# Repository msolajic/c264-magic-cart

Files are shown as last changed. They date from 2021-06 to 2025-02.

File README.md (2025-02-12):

# c264-magic-cart
Hardware design of a cartridge for the Commodore 264 series of computers - Commodore 16, 116 and plus/4

This is the hardware part that accompanies the project of [Magic Cartridge Generator](https://bitbucket.org/zzarko/magic-cartridge-generator/)

This project is free to use and you can use any PCB manufacturer by downloading the Gerber files, but if you would like to support my work and help with further hardware development you can order these PCBs on PCBWay trough this link:

PCB from PCBWay (https://www.pcbway.com/project/shareproject/Commodore_264_Series_Magic_Cartridge.html)

You will get cheap and professionally made PCBs, I will get credits that will help with this and [other projects](https://www.pcbway.com/project/member/?bmbno=1DE407A1-1650-47). Also, if you have to register to that site, [you can use this link](https://pcbway.com/g/YFnBAc) to get bonus initial credit.

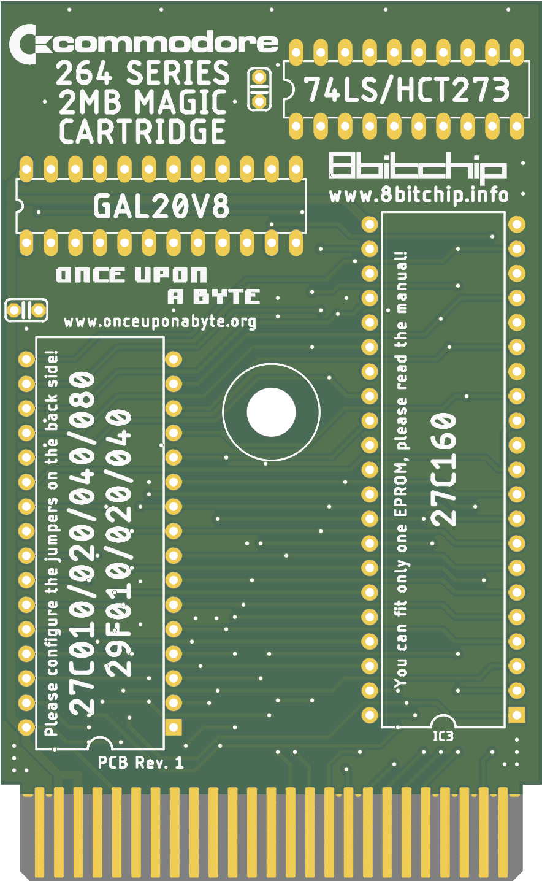
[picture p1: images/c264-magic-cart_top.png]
PCB Top


Hardware Description
--------------------

Original Commodore 264 cartridges could be up to 32 Kb in size, in two separate banks of 16Kb. This cartridge implements a latch which is tied to a memory address, so it can address (in this incarnation) up to 2 megabytes of data (128 banks of 16Kb). In that regard, it is very similar to Magic Desk or Ocean cartridges for the Commodore 64.

EPROM is selected by the C1LO selection line coming from the computer, and the 16k of data from the selected bank is visible in the memory map at addresses $8000 - $BFFF.

Inputs of an 8-bit latch (74LS273) are connected to the data lines. A GAL20V8 is responsible for decoding writes to a memory address by decoding the full address bus. Decoder has the option of decoding several frequently used addresses for banking cartridges, since there is no standard address defined. This cartridge is primarily designed to enable making onefile program compilations through the [Magic Cartridge Generator](https://bitbucket.org/zzarko/magic-cartridge-generator/).

The PCB was designed to accommodate various types of EPROMs and their FLASH variants. The smallest EPROM you can use is 27C010 (128Kb), and the largest is 27C160 (2Mb). There are two EPROM sockets, but you cannot use both at the same time. The left socket accepts standard 8-bit EPROMs and their FLASH variants (27C010 to 27C080) and the right socket is for 27C160 (16-bit EPROM in 8-bit mode).

Address decoder
---------------

The address decoder is implemented in GAL20V8. All 16 address lines, /PHI2 and /RW are connected to the GAL to enable single-address decoding. Of course, a GAL16V8 could have been used, but it would only be capable of decoding an address in 16-byte blocks, or the address decoder could be implemented in TTL logic which would require at least 3 ICs. Two spare inputs were used to create a selection jumper to select between four commonly used addresses for cartridge banking. The default address used is $FDFE, which is mentioned in the document at http://solder-synergy.de/plus4/hardware/makers/ioarea.txt as "Register on EPROM-card". Other addresses which can be configured are $FE00 (used on a Hungarian homebrew cartridge found at https://www.commodoreszerviz.hu/commodore_16-116-plus_4_1mb_cartridge_juhasz_jacint.htm), $FDA0 used by another homebrew cartridge, and $FD17 which is also mentioned in the document above as "Register for EPROM-/sRAM-expansion". 

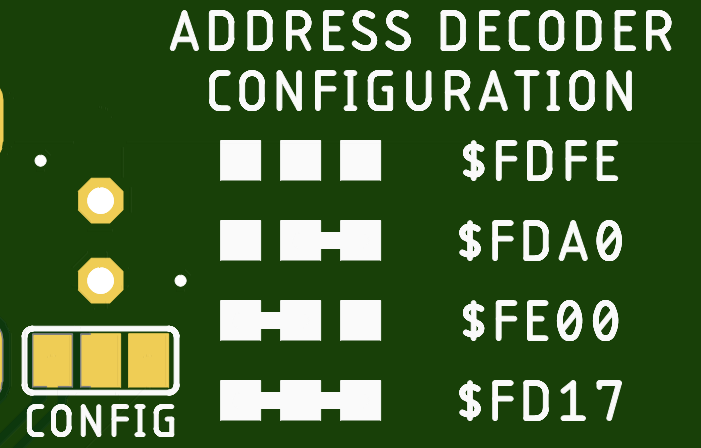
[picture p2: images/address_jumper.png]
Address selection jumper


The address decoder is configured with a solder-jumper on the bottom side of the PCB. The configuration legend is also shown at the bottom. Use extreme care when trying to bridge the pads (if needed, as the default configuration is already selected when the jumper is open) because you can easily lift the pads with excess heat.

EPROM selection jumpers
-----------------------

In order to support most common types of EPROMs and FLASH EPROMs, two solder jumpers have been placed on the bottom side of the PCB. They look like this:

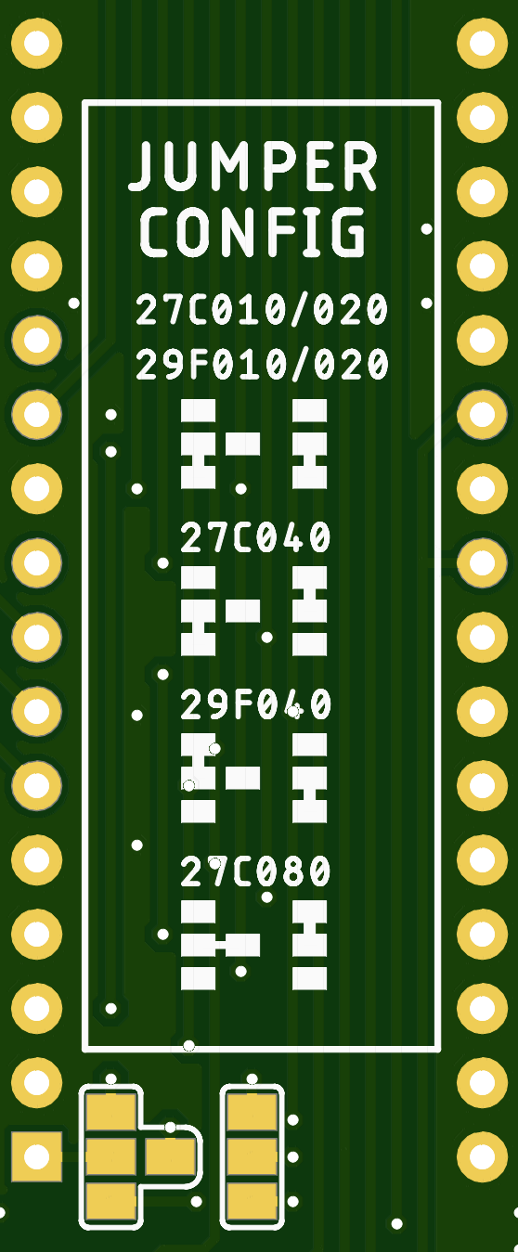
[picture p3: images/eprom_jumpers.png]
EPROM selection jumpers


These jumpers HAVE to be configured before plugging the cartridge to your computer! Different types of EPROMs and their FLASH variants have some pins swapped, and if you are using a chip smaller than the maximum size, the unused address lines have to be pulled high on the EPROM side to ensure proper functioning.

You can use either the left 32-pin socket, or the right 42-pin socket, but never the both at the same time. The right socket is meant for using the 2Mb 27C160 EPROMs. This is a 16-bit EPROM but it can be forced to work in 8-bit mode by connecting the BYTE/Vpp pin to ground. In that configuration, the address lines are shifted by one and the output Q15 is used as address line A0. These 16-bit EPROMs are not directly supported by the popular TL866 programmer, and have to be programmed through an adapter, in multiple passes. An example adapter can be found [here](https://github.com/mafe72/27c160-tl866-adapter) or [here](https://github.com/gaggi/27c160-tl866-adapter)

GAL programming
---------------

In the GAL folder there are both .pld and .jed files provided for GAL programming. You can also use a programmer such as TL866 to program the GAL. If you want to change anything in the decoder, you can use [GALASM](https://github.com/daveho/GALasm) to recompile the .pld file. 

Capacitors
----------

The capacitors are not needed, but you can populate them. They are 100nF 50V MLCC or ceramic capacitors with 2.54mm raster.

Enclosure compatibility
-----------------------

The PCB is designed to be as close in dimensions as the original Commodore PCB, so you can re-use an original Commodore cartridge case, or you can 3D-print one. Compatible designs are available on Thingiverse, such as [this one](https://www.thingiverse.com/thing:3657002) or [this one](https://www.thingiverse.com/thing:4627130). Unfortunately, no one makes injection-moulded cartridge cases for the 264 series anymore.

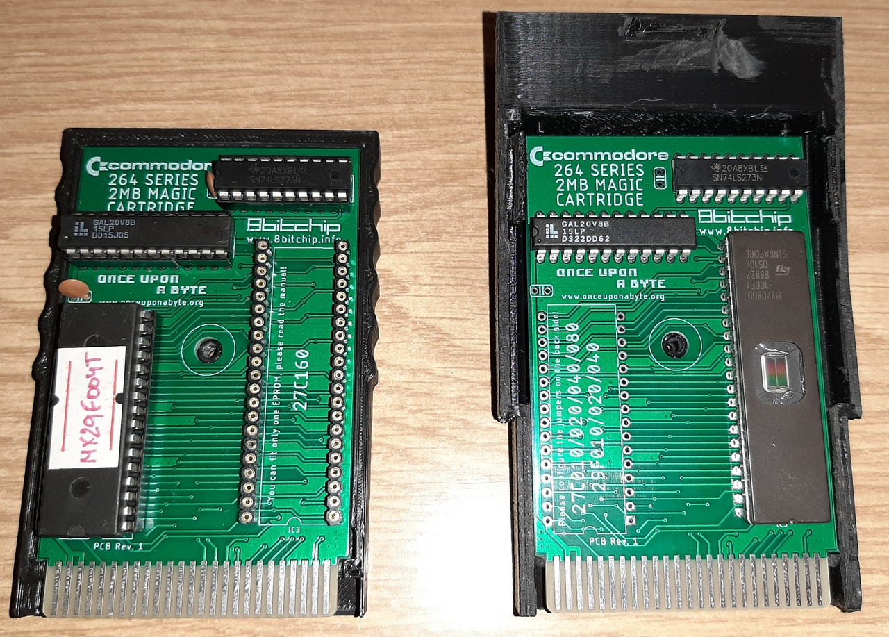
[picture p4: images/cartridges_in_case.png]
cartridges_in_case


Revision history
----------------

- Rev.1
    - Initial release

Changelog
---------

- February 11th, 2022:
    - Added EAGLE schematic and board files
    
Thanks:
-------

My thanks go to:

- Žarko Živanov, for creating the Magic Cartridge Generator
- Everyone from [Plus/4 World](http://plus4world.powweb.com/) for help with hardware and software specifics
- Groepaz from the [VICE Team](https://vice-emu.sourceforge.io/), for adding the cartridge support in VICE (currently available only in nightly builds)
- Jim Drew and the CRX crew
- Everyone who ordered any of my PCBs from PCBWay
- and all other people in the Commodore 64 community that I forgot to mention, you guys are awesome!

License
-------
c264-magic-cart is Open Hardware licensed under the [CERN OHL v. 1.2](http://ohwr.org/cernohl), released by Marko Šolajić in 2021. You may redistribute and modify this documentation under the terms of the CERN OHL v.1.2.

A copy of the full license is included in file [LICENSE.txt](LICENSE.txt)

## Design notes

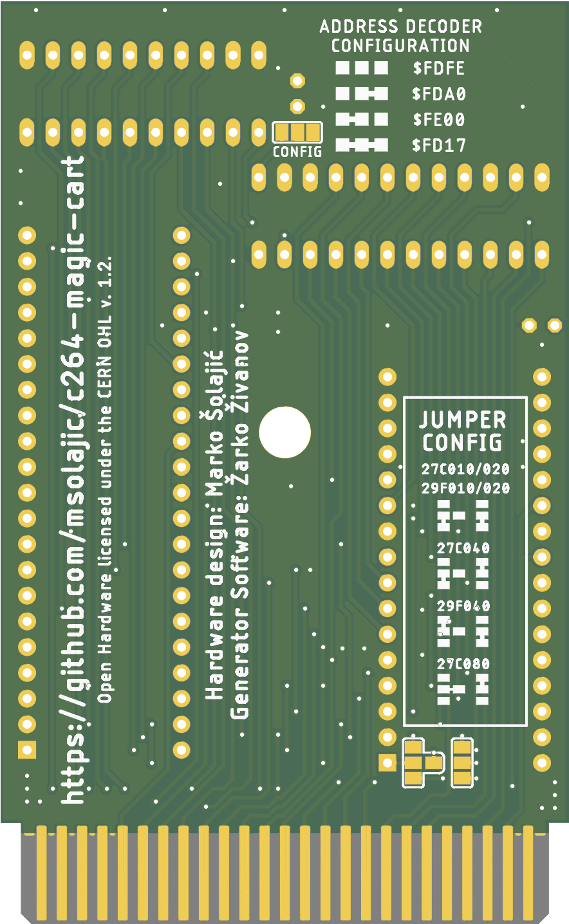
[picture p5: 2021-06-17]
images/c264-magic-cart_bot.png

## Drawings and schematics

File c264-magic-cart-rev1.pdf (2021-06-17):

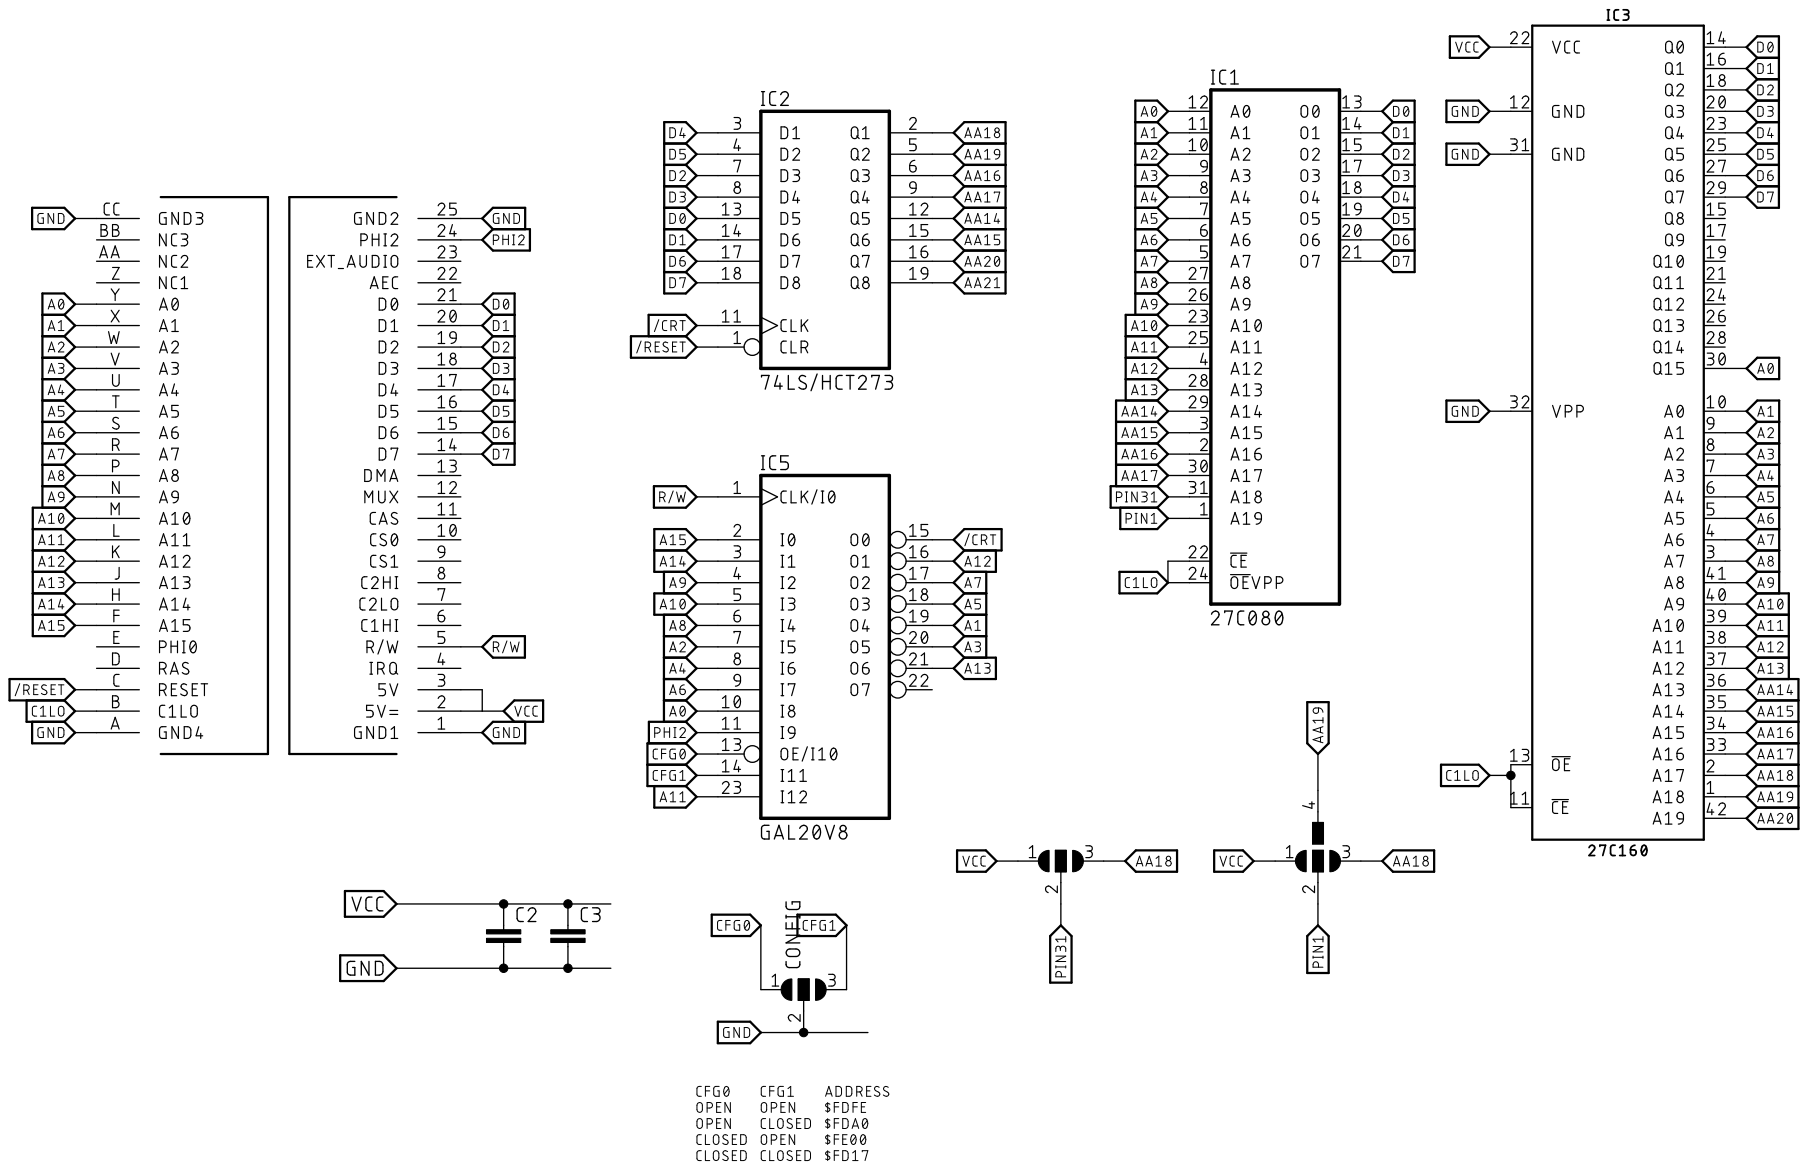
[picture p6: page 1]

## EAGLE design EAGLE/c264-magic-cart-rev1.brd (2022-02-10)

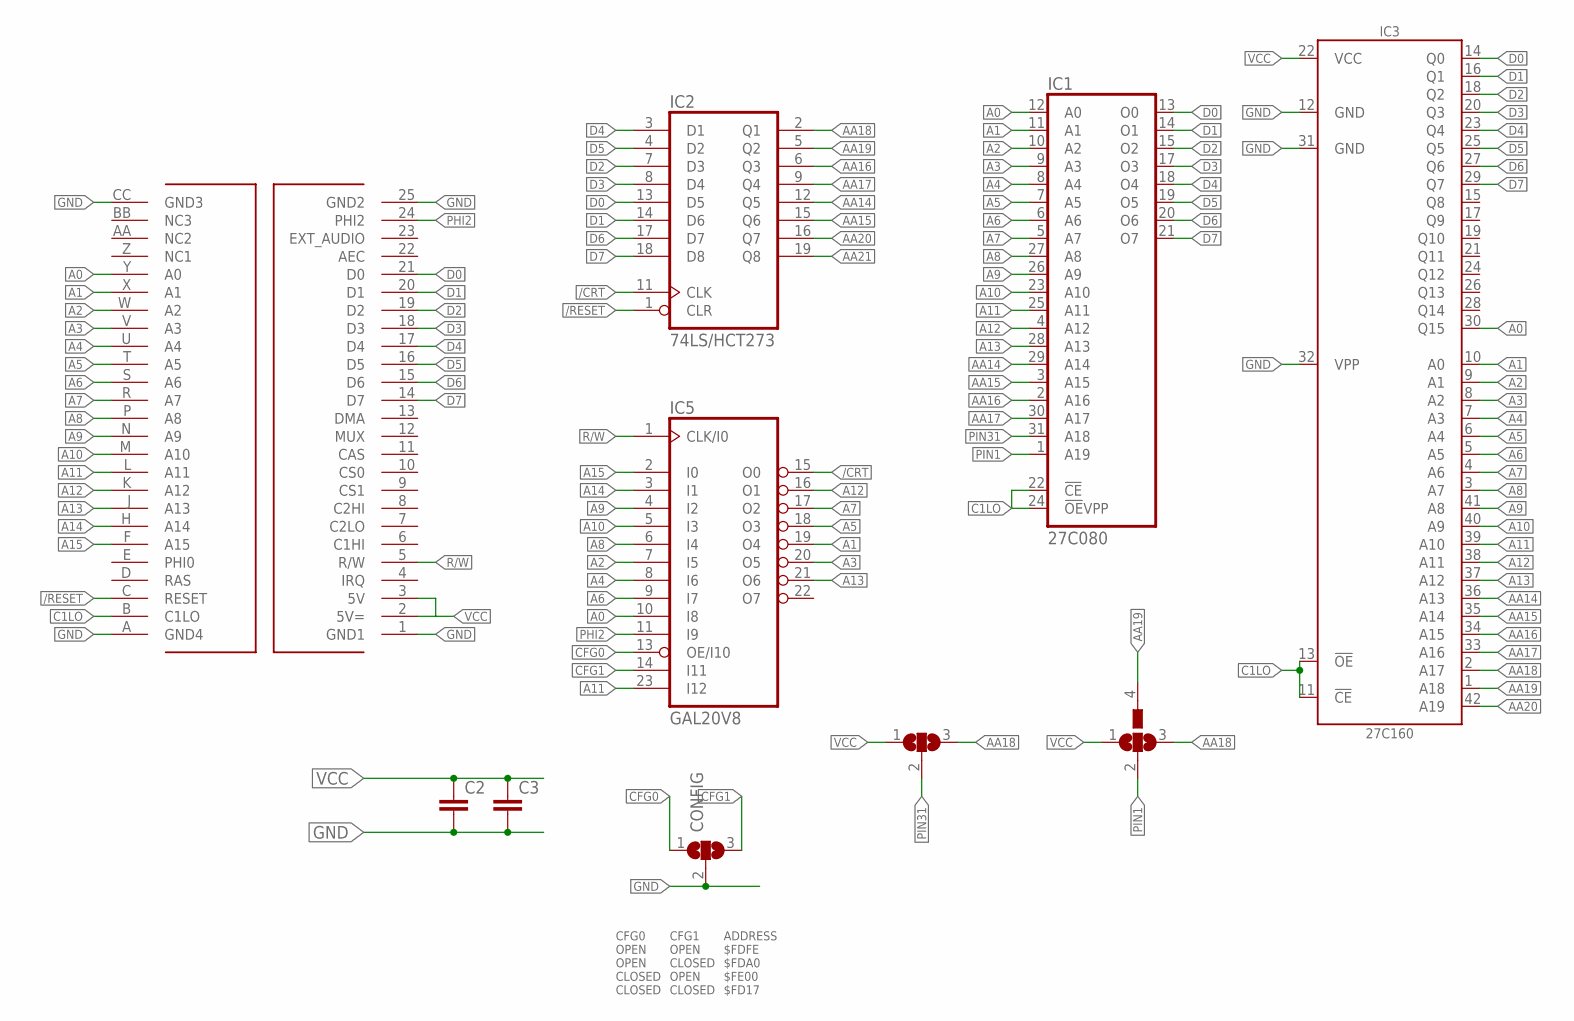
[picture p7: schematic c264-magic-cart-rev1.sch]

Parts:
C2, C3: C-EU025-024X044; C025-024X044
CONFIG: SJ2W; SJ_2
IC1: 27C080; DIL32
IC2: 74LS/HCT273; DIL20
IC3: 27C160; DIP42
IC5: GAL20V8; DIL24-3
SJ1: SJ2W; SJ_2
U$1: C16_CARTRIDGE; C16_CART
U$2: SJ3; SJ_3

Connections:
/CRT: IC2.11 (CLK), IC5.15 (O0)
/RESET: IC2.1 (CLR), U$1.C (RESET)
A0: IC1.12 (A0), IC3.30 (Q15), IC5.10 (I8), U$1.Y (A0)
A1: IC1.11 (A1), IC3.10 (A0), IC5.19 (O4), U$1.X (A1)
A2: IC1.10 (A2), IC3.9 (A1), IC5.7 (I5), U$1.W (A2)
A3: IC1.9 (A3), IC3.8 (A2), IC5.20 (O5), U$1.V (A3)
A4: IC1.8 (A4), IC3.7 (A3), IC5.8 (I6), U$1.U (A4)
A5: IC1.7 (A5), IC3.6 (A4), IC5.18 (O3), U$1.T (A5)
A6: IC1.6 (A6), IC3.5 (A5), IC5.9 (I7), U$1.S (A6)
A7: IC1.5 (A7), IC3.4 (A6), IC5.17 (O2), U$1.R (A7)
A8: IC1.27 (A8), IC3.3 (A7), IC5.6 (I4), U$1.P (A8)
A9: IC1.26 (A9), IC3.41 (A8), IC5.4 (I2), U$1.N (A9)
A10: IC1.23 (A10), IC3.40 (A9), IC5.5 (I3), U$1.M (A10)
A11: IC1.25 (A11), IC3.39 (A10), IC5.23 (I12), U$1.L (A11)
A12: IC1.4 (A12), IC3.38 (A11), IC5.16 (O1), U$1.K (A12)
A13: IC1.28 (A13), IC3.37 (A12), IC5.21 (O6), U$1.J (A13)
A14: IC5.3 (I1), U$1.H (A14)
A15: IC5.2 (I0), U$1.F (A15)
AA14: IC1.29 (A14), IC2.12 (Q5), IC3.36 (A13)
AA15: IC1.3 (A15), IC2.15 (Q6), IC3.35 (A14)
AA16: IC1.2 (A16), IC2.6 (Q3), IC3.34 (A15)
AA17: IC1.30 (A17), IC2.9 (Q4), IC3.33 (A16)
AA18: IC2.2 (Q1), IC3.2 (A17), SJ1.3, U$2.3
AA19: IC2.5 (Q2), IC3.1 (A18), U$2.4
AA20: IC2.16 (Q7), IC3.42 (A19)
AA21: IC2.19 (Q8)
C1LO: IC1.22 (!CE), IC1.24 (!OE!VPP), IC3.11 (!CE), IC3.13 (!OE), U$1.B (C1LO)
CFG0: CONFIG.1, IC5.13 (OE/I10)
CFG1: CONFIG.3, IC5.14 (I11)
D0: IC1.13 (O0), IC2.13 (D5), IC3.14 (Q0), U$1.21 (D0)
D1: IC1.14 (O1), IC2.14 (D6), IC3.16 (Q1), U$1.20 (D1)
D2: IC1.15 (O2), IC2.7 (D3), IC3.18 (Q2), U$1.19 (D2)
D3: IC1.17 (O3), IC2.8 (D4), IC3.20 (Q3), U$1.18 (D3)
D4: IC1.18 (O4), IC2.3 (D1), IC3.23 (Q4), U$1.17 (D4)
D5: IC1.19 (O5), IC2.4 (D2), IC3.25 (Q5), U$1.16 (D5)
D6: IC1.20 (O6), IC2.17 (D7), IC3.27 (Q6), U$1.15 (D6)
D7: IC1.21 (O7), IC2.18 (D8), IC3.29 (Q7), U$1.14 (D7)
GND: C2.2, C3.2, CONFIG.2, IC1.16 (GND), IC2.10 (GND), IC3.12 (GND), IC3.31 (GND), IC3.32 (VPP), IC5.12 (GND), U$1.1 (GND1), U$1.25 (GND2), U$1.A (GND4), U$1.CC (GND3)
PHI2: IC5.11 (I9), U$1.24 (PHI2)
PIN1: IC1.1 (A19), U$2.2
PIN31: IC1.31 (A18), SJ1.2
R/W: IC5.1 (CLK/I0), U$1.5 (R/W)
VCC: C2.1, C3.1, IC1.32 (VCC), IC2.20 (VCC), IC3.22 (VCC), IC5.24 (VCC), SJ1.1, U$1.2 (5V=), U$1.3 (5V), U$2.1

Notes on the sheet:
CFG0 OPEN OPEN CLOSED CLOSED
CFG1 OPEN CLOSED OPEN CLOSED
ADDRESS $FDFE $FDA0 $FE00 $FD17

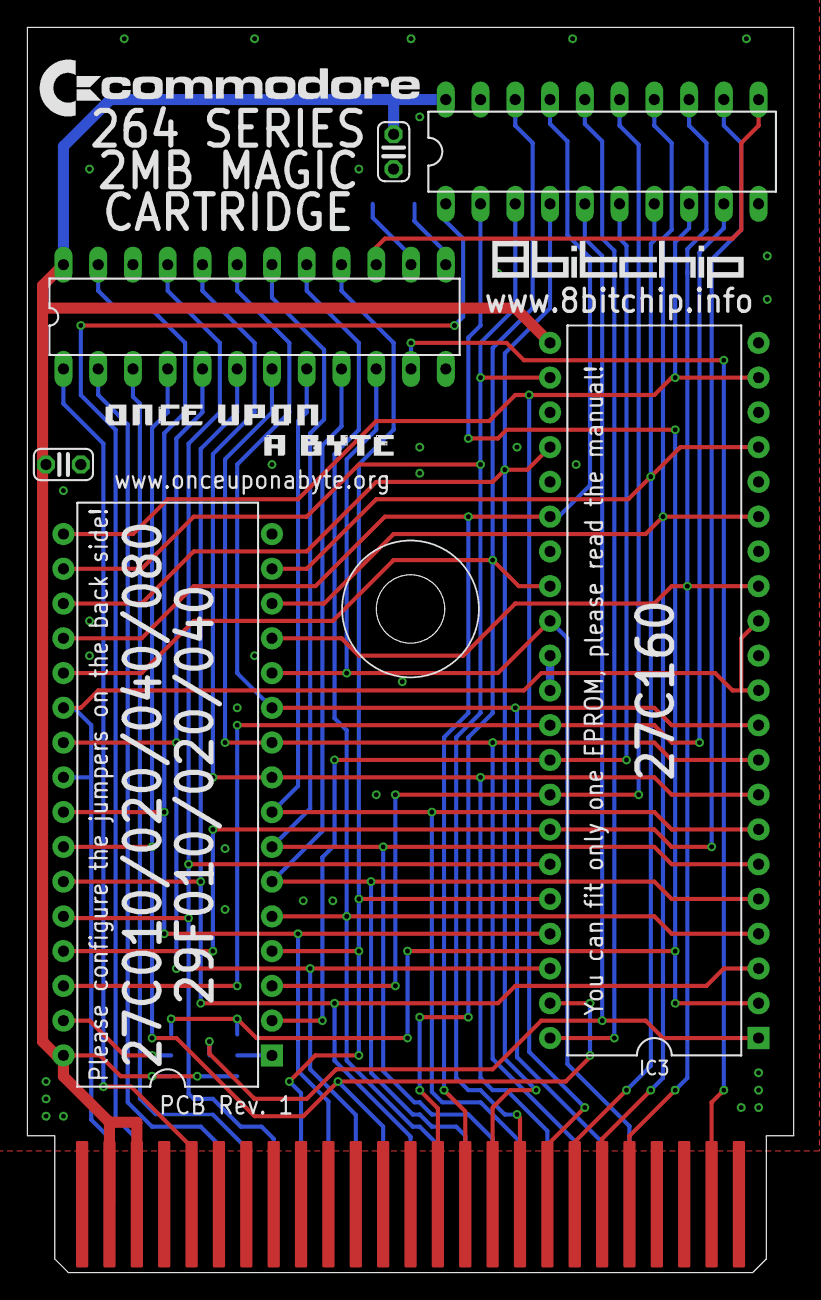
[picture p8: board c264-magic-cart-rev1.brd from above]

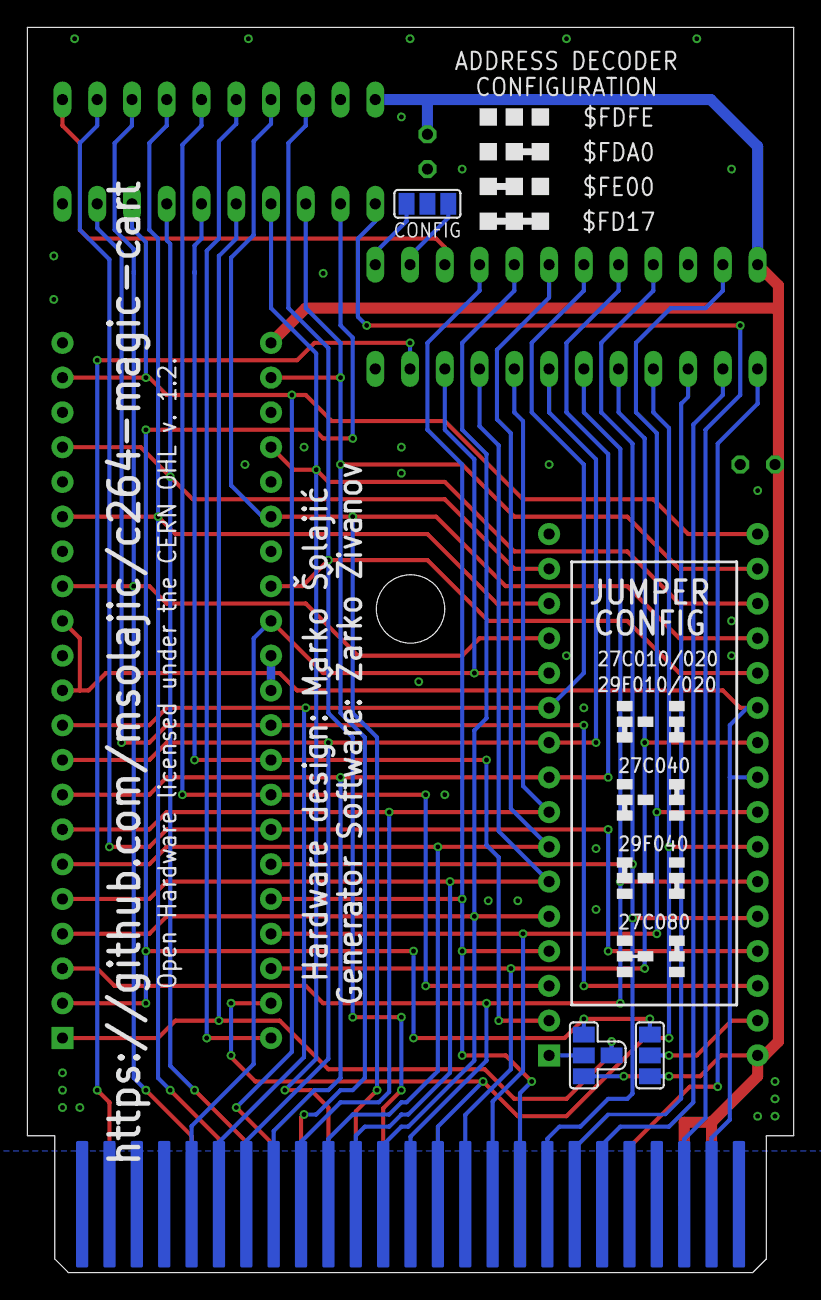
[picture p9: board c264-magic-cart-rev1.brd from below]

Board: 2 copper layers, 56.0 x 91.0 mm, 10 parts (3 on the bottom side), 42 nets.

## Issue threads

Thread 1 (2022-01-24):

Help me i can't get it to work

danko79, 2022-01-24:
Hi,i need help with this cartridge programmed the GAL20V8B-15LP set the jumpers for AM26F040B and make a 512KB file with prg games with zzarko-magic-cartridge-generator-fa8be5cd43f2 but when insert the cartridge it does not work, tested your other cartridges with success.

https://i.postimg.cc/tTB5dr2J/c264-front.jpg
https://i.postimg.cc/Y9rRWcNT/c264-back.jpg

msolajic, 2022-01-24:
Can you test the binary compilation file with VICE 3.6? This will rule out software issues, at least.

danko79, 2022-01-24:
Hi,yes test the .BIN file with GTK3VICE-3.6.0-win64 same
problem,attach the file .bin and .prg pack.
Please let me know!

Il
24.01.2022 14:03 Marko Šolajić ha scritto:

> Can you test the binary
compilation file with VICE 3.6? This will rule out software issues, at
least.
>
> --
> Reply to this email directly, view it on GitHub [1],
or unsubscribe [2].
> You are receiving this because you authored the
thread.Message ID: @github.com>

Con Tiscali Mobile Smart 70 hai 70 GB in 4G, minuti illimitati e 100 SMS a soli 7,99€ al mese http://tisca.li/Smart70

zzarko, 2022-01-24:
Can you send your whole directory with generator script, cartridge
configuration, prg files and generated BIN file? Then I can check what the
problem is.
Also, send the exact command line you used to generate BIN file.

Cheers,
Žarko

*Sent from my Commodore 64*

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

danko79, 2022-01-24:
ok the script is "python crtgen.py -c" in attach my directory,can you
create a file for me so i see if it works?

Il 24.01.2022 15:06 zzarko
ha scritto:

> Can you send your whole directory with generator script,
cartridge
> configuration, prg files and generated BIN file? Then I can
check what the
> problem is.
> Also, send the exact command line you
used to generate BIN file.
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
Commodore 64*
>
> On Mon, Jan 24, 2022 at 2:12 PM danko79 ***@***.***>
wrote:
>
> >
> > Hi,yes test the .BIN file with GTK3VICE-3.6.0-win64
same
> > problem,attach the file .bin and .prg pack.
> > Please let me
know!
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
rule out software issues, at
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
this email directly, view it on GitHub [1],
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
@github.com>
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
4G, minuti illimitati e 100 SMS a
> > soli 7,99EUR al mese
http://tisca.li/Smart70
> >
> > --
> > Reply to this email directly,
view it on GitHub
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
notifications on the go with GitHub Mobile for iOS
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
thread.Message
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
directly, view it on GitHub [1], or unsubscribe [2].
> You are receiving
this because you authored the thread.Message ID: @github.com>

Con Tiscali Mobile Smart 70 hai 70 GB in 4G, minuti illimitati e 100 SMS a soli 7,99€ al mese http://tisca.li/Smart70

zzarko, 2022-01-24:
Yes, that was exactly why I wanted to see the exact command line. "-p" is
the correct option.

Regarding the games that do not work, I found these:
Auto Zone.prg
Exploding Fist.prg
Invaders Live Wire.prg
Joey.prg
Kane.prg
Kingsoft Tennis.prg
Leapinlouie.prg
Monkey Kong.prg
Monster Hunter.prg
Oneman And His Droid.prg
Pac Mac.prg
Return Of Rockman.prg

Some of them have non-standard loading address (standard is $1001 or
$4001), for those you need to supply start address:
Invaders Live Wire.prg
Kingsoft Tennis.prg
Monkey Kong.prg

As for the rest, they do not work in xplus4 emulator (3.6.1) at all (at
least on my computer, when started directly as PRG files), so there is no
way that they could work from cartridge in xplus4:
Auto Zone.prg
Exploding Fist.prg
Joey.prg
Kane.prg
Kingsoft Tennis.prg
Leapinlouie.prg
Monster Hunter.prg
Oneman And His Droid.prg
Pac Mac.prg
Return Of Rockman.prg
They might work on a real Plus/4, but you'll need to check that.

Cheers,
Žarko

*Sent from my Commodore 64*

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

danko79, 2022-01-24:
Many thanks for your support! as soon as I have some time I text them all, thanks for your patience!

danko79, 2022-01-30:
Hi,I found that some games that play but only if it is the first on
the list, I tried to replicate the same game 5/6 times to create a 64KB
file the cartridge works but of the same game only the first one doesn't
seem strange to you?
can you try too?

Il 24.01.2022 20:44 Marko
Šolajić ha scritto:

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
directly, view it on GitHub [2], or unsubscribe [3].
> You are receiving
this because you authored the thread.Message ID: @github.com>

Con Tiscali Mobile Smart 70 hai 70 GB in 4G, minuti illimitati e 100 SMS a soli 7,99€ al mese http://tisca.li/Smart70

zzarko, 2022-01-30:
Send me an archive with everything (like before), tell me how exactly to
reproduce the problem, and I can take a look.

Cheers,
Žarko

*Sent from my Commodore 64*

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

danko79, 2022-01-30:
Hi, I've done a lot of tests! and understood that the games work as long as it is the first on list otherwise it doesn't work anymore, i make a 3 different BIN files 128KB has a different primary game as you can verify it works too all the games below do not works only if you make it happen first, i used a W27C010-15 flash for test all.
the command used is python crtgen.py -p

http://www.easybytez.com/rdnzr148nvzw

Please let me know,I can't understand why it does this.

msolajic, 2022-01-30:
Hi, i did some tests with your 128k images, and all of them work well. I tested with 29EE010 flash which is the same pinout as W27C010. To me, this looks like a banking issue, because the menu and the first game (either one of those in the archive) are less than 16 kilobytes in total. So, please check the GAL or 74LS273, as they are the most likely problem.

msolajic, 2022-01-30:
Also, is the GAL programmed and verified? Because I'm getting the same behaviour as yours without the GAL inserted on the board. Without it, only the first game works.

danko79, 2022-01-30:
The GAL programmed several times, if my images works i can try to replace the 74ls273,then I will let you know.

danko79, 2022-01-30:
Hi,i try to replace 74LS273 same problem,when replace GAL with another one programmed cartridge works fine!
Many thanks!!!!!

msolajic, 2022-01-30:
You're welcome.

danko79, 2022-03-06:
Hi,sorry if re-open this, but it is the only way to contact you, I wanted to know if these are compatible the GAL20V8QS-15LNC. Regards

Closed 2022-01-30.
